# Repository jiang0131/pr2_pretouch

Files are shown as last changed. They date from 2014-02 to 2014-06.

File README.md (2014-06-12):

This repository includes components of pretouch sensing related packages that use ROS:

* **pr2_pretouch_seashell_sensors**: seashell pretouch sensor nodes
* **pr2_pretouch_optical_sensors**:	optical pretouch sensor nodes
* **pr2_pretouch_msgs**: pretouch sensor related messages
* **pr2_gripper_firmware**: the picoblaze and atmega microcontroller firmwares for the pretouch sensors
* **pr2_pretouch_sensor_hardware**: sensor hardware design files (PCB, mechanical model)
* **pr2_pretouch_grasp**: pretouch assisted grasping application

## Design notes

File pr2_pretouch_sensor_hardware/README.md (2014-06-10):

fixture_solidworks: Contains the PR2 finger mechanical design files in Solidworks for each of the pretouch sensors, so the PCB and sensor components can be fixed/mounted on the fixure.

pcb_altium: Contains the schematics and PCB layout files in Altium for each of the pretouch sensors. Bill of Materials are also included.

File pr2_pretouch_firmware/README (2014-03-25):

- seashell_effect     -- Firmware of Seashell Effect Pretouch Sensor
    + microcontroller     -- ATmega168/328 fimware
    + picoblaze           -- PicoBlaze firmware
- optical_ir          -- Firmware of Optical IR Pretouch Sensor
    + microcontroller     -- ATmega168/328 fimware
    + picoblaze           -- PicoBlaze firmware
- wg006_gripper       -- Firmware of the FPGA on the MCB of PR2 grippers which supports PicoBlaze (PicoBlaze supported >2.0)

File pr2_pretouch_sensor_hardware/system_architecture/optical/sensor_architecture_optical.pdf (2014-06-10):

Analog Signal | Digital Signal

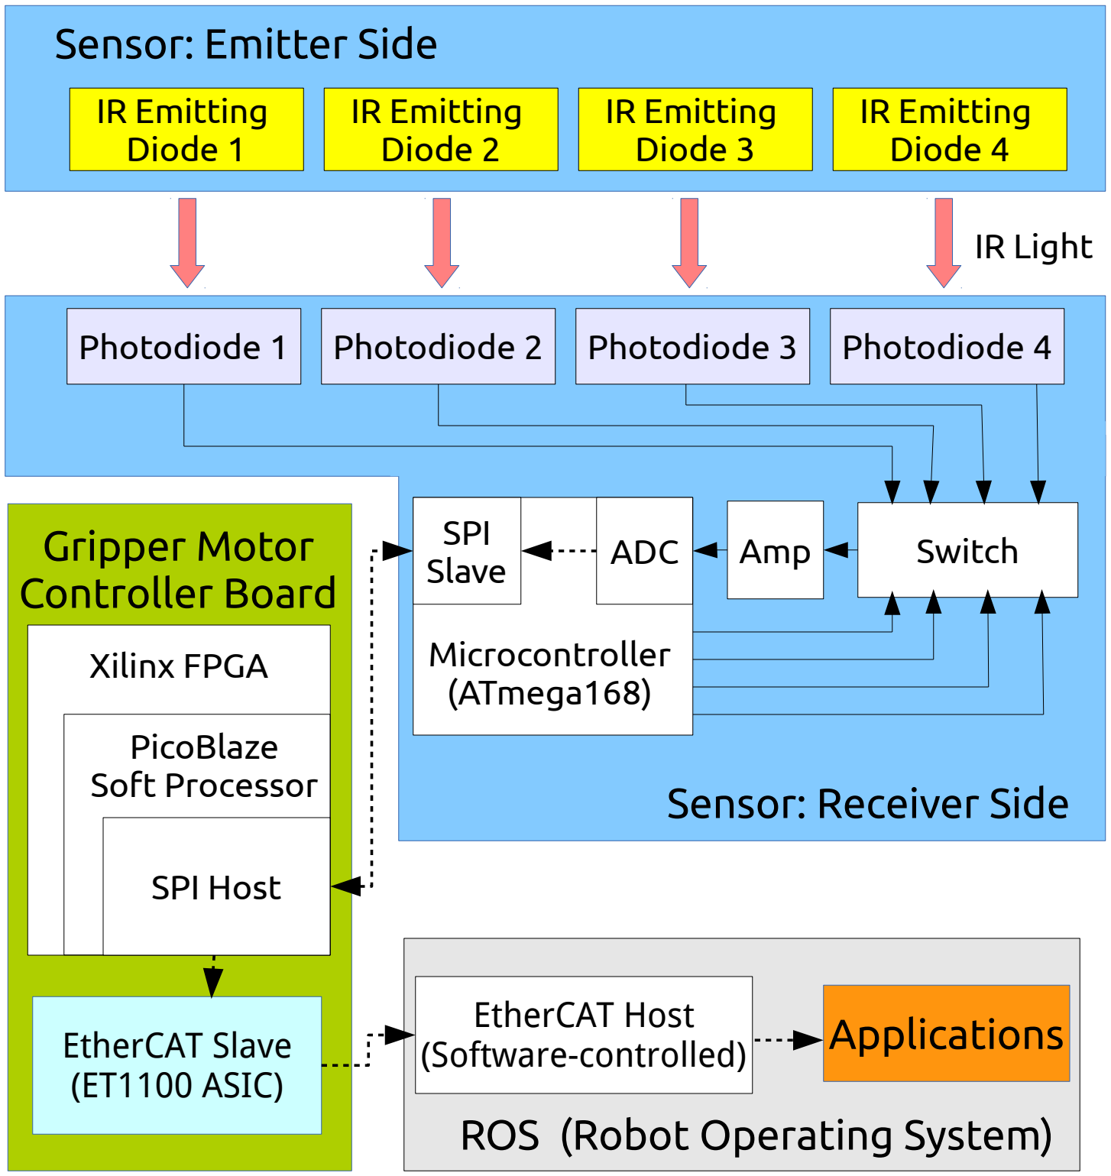
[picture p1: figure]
Gripper Motor Controller Board; Switch; Xilinx FPGA; PicoBlaze Soft Processor; SPI Host; EtherCAT Host (Software-controlled) EtherCAT Slave (ET1100 ASIC); ROS (Robot Operating System); Microcontroller (ATmega168); ADC SPI Slave; Applications; IR Emitting Diode 1; Photodiode 1; IR Emitting Diode 2; Photodiode 2; IR Emitting Diode 3; Photodiode 3; IR Emitting Diode 4; Photodiode 4; Amp; Sensor: Emitter Side; Sensor: Receiver Side; IR Light

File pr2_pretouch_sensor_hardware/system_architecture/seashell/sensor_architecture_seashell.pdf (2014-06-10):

Analog Signal | Digital Signal

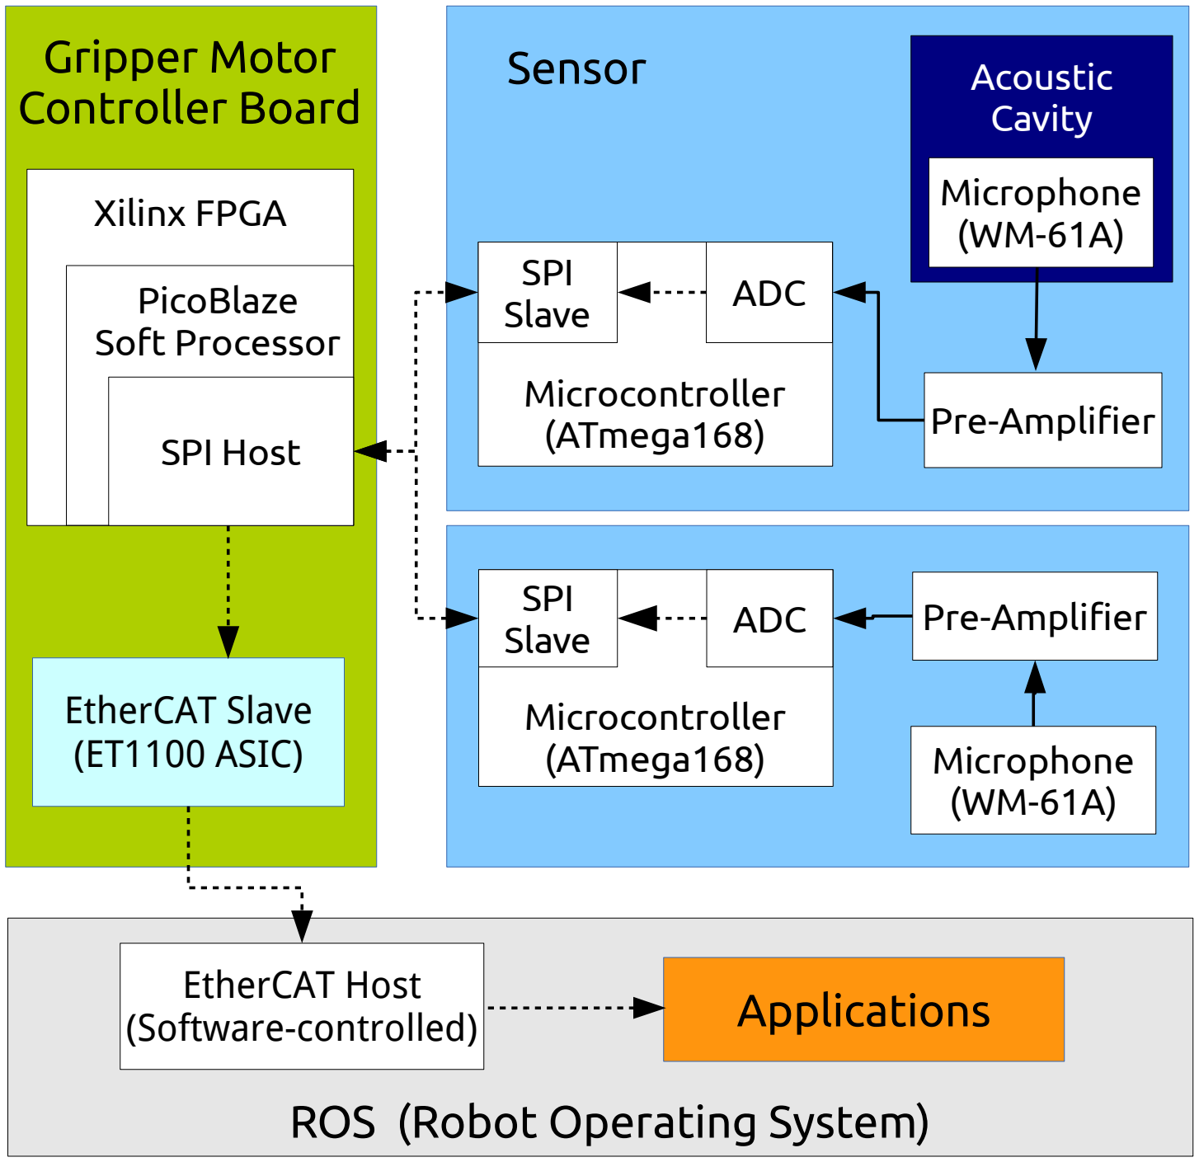
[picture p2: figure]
Gripper Motor; Controller Board; Acoustic; Cavity; Microphone (WM-61A); Pre-Amplifier; Xilinx FPGA; PicoBlaze Soft Processor; SPI Host; EtherCAT Host (Software-controlled); EtherCAT Slave (ET1100 ASIC); ROS (Robot Operating System); Microcontroller (ATmega168); ADC SPI Slave; Applications; Sensor

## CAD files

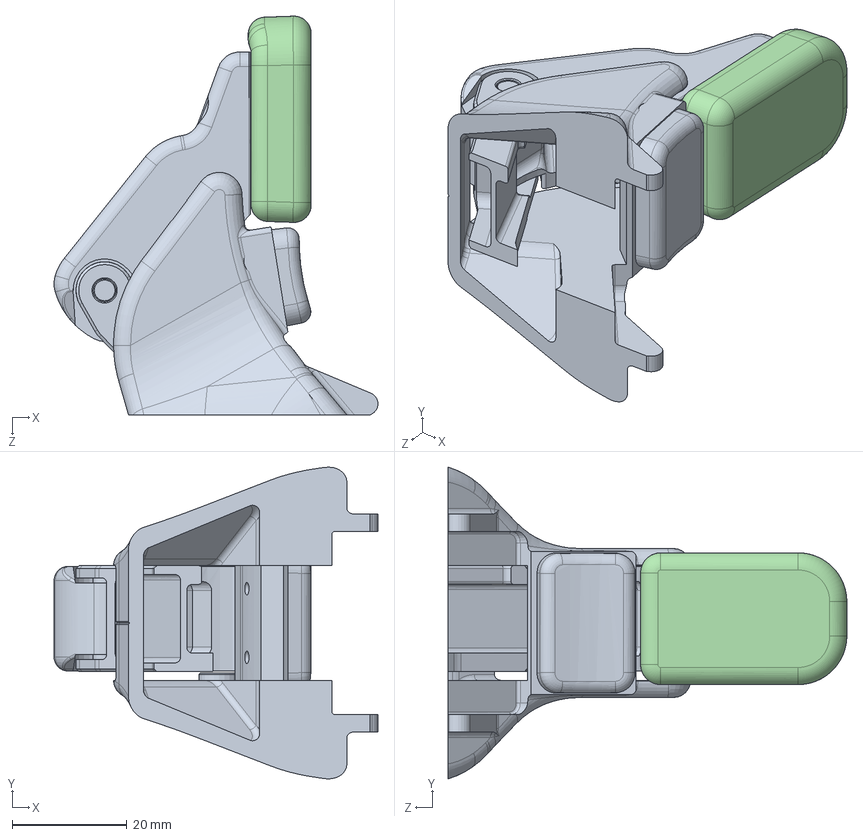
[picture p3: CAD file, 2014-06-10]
pr2_pretouch_sensor_hardware/fixture_solidworks/fixture_solidworks_pr2_original/PR2_MODULARITY_GRPR_ASM.sldasm
56.5 x 54.4 x 69.6 mm
PR2_MODULARITY_GRPR
SCR_SHCS_M3_050_8_SST_A2-70 x 4
PR2_HAND_FINGER_CORE
PR2_HAND_FINGER_RUBBER

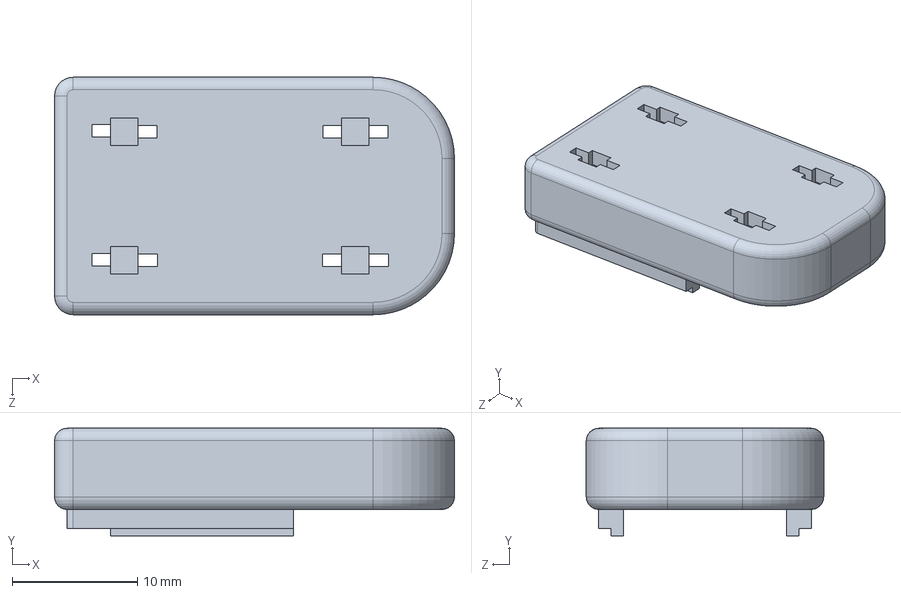
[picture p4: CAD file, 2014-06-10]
pr2_pretouch_sensor_hardware/fixture_solidworks/fixture_solidworks_optical/pr2_finger_optical.SLDPRT
32.0 x 8.60 x 19.0 mm

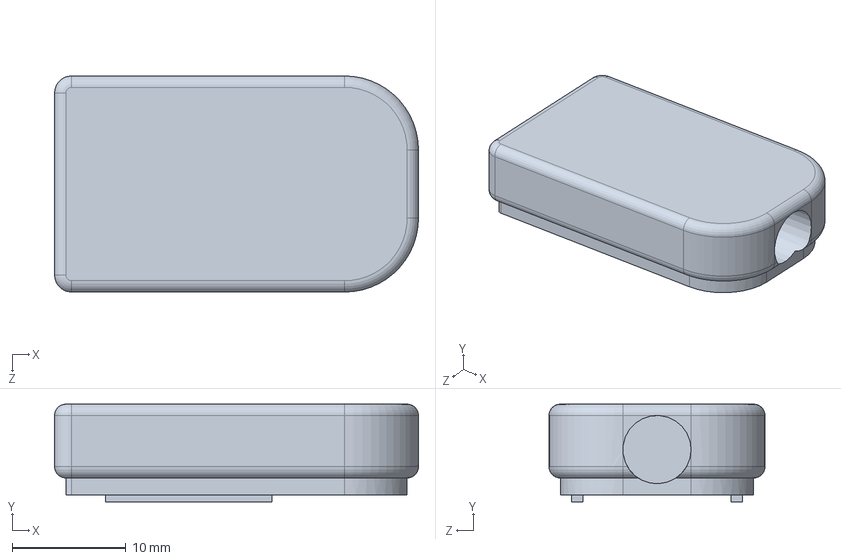
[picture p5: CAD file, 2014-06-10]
pr2_pretouch_sensor_hardware/fixture_solidworks/fixture_solidworks_seashell/pr2_finger_seashell_reference.SLDPRT
32.0 x 8.60 x 19.0 mm

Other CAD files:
pr2_pretouch_sensor_hardware/fixture_solidworks/fixture_solidworks_pr2_original/PR2_MODULARITY_GRPR.sldprt
pr2_pretouch_sensor_hardware/fixture_solidworks/fixture_solidworks_seashell/pr2_finger_seashell_sensing.SLDPRT

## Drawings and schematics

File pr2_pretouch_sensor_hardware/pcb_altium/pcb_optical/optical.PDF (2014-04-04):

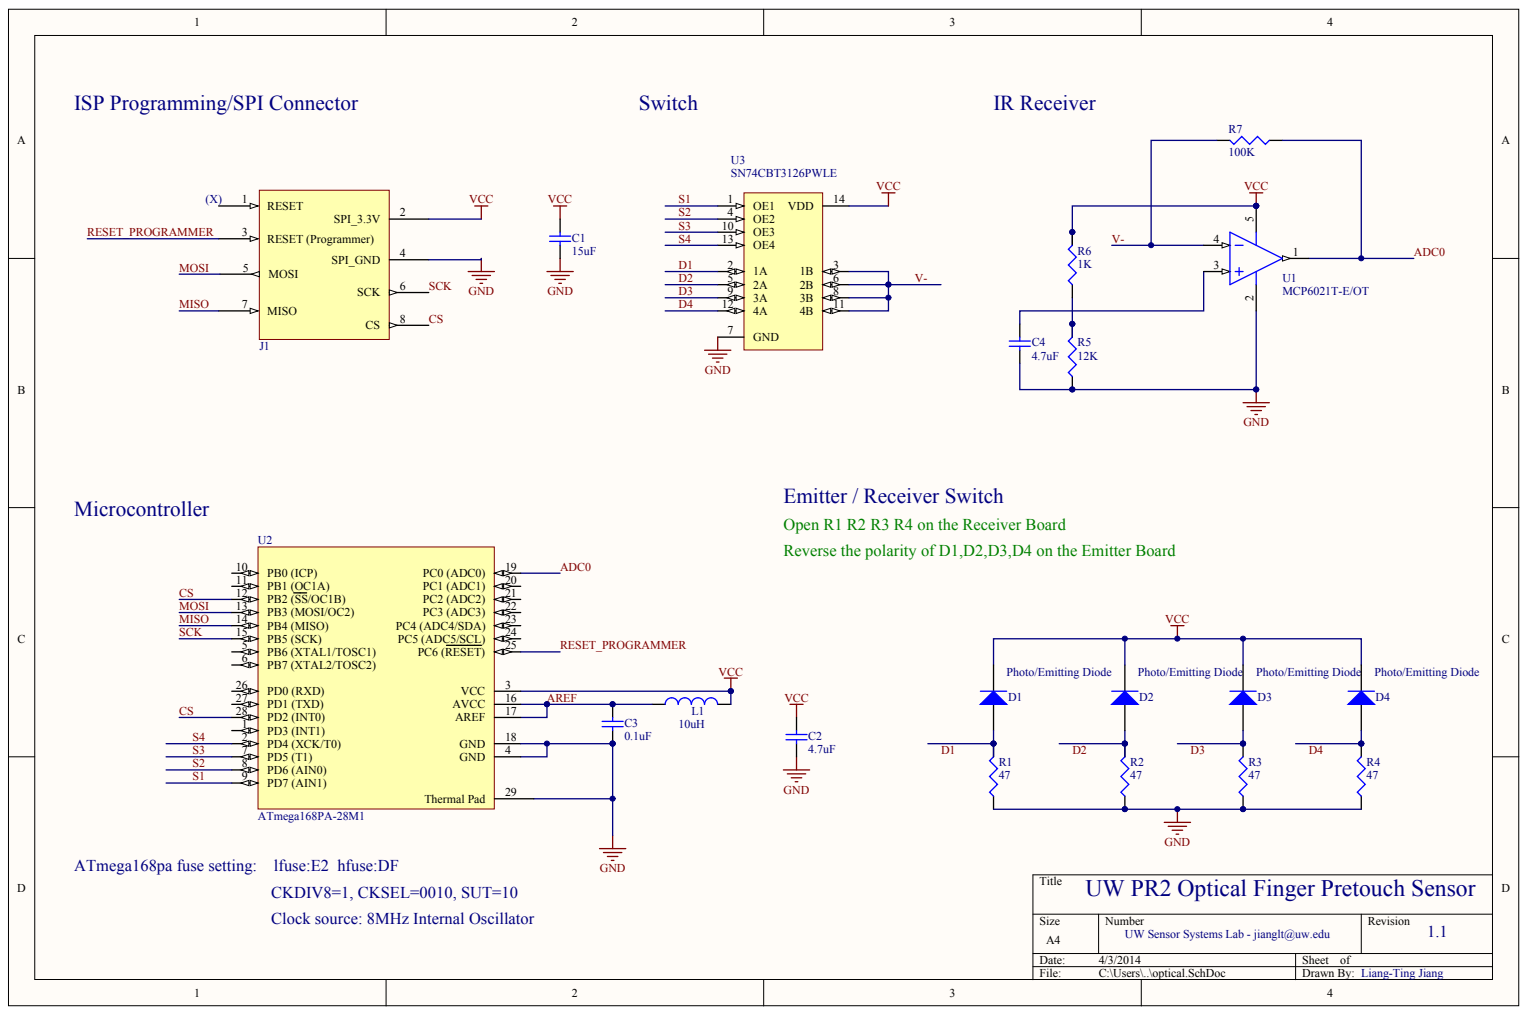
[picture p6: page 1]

ISP Programming/SPI Connector

Open R1 R2 R3 R4 on the Receiver Board
Reverse the polarity of D1,D2,D3,D4 on the Emitter Board

ATmega168pa fuse setting: lfuse:E2 hfuse:DF

Title
UW PR2 Optical Finger Pretouch Sensor

CKDIV8=1, CKSEL=0010, SUT=10
Clock source: 8MHz Internal Oscillator

Size A4 | Number UW Sensor Systems Lab - jianglt@uw.edu | Revision 1.1

Date: 4/3/2014 | Sheet of
File: C:\Users\. .\optical.SchDoc | Drawn By: Liang-Ting Jiang

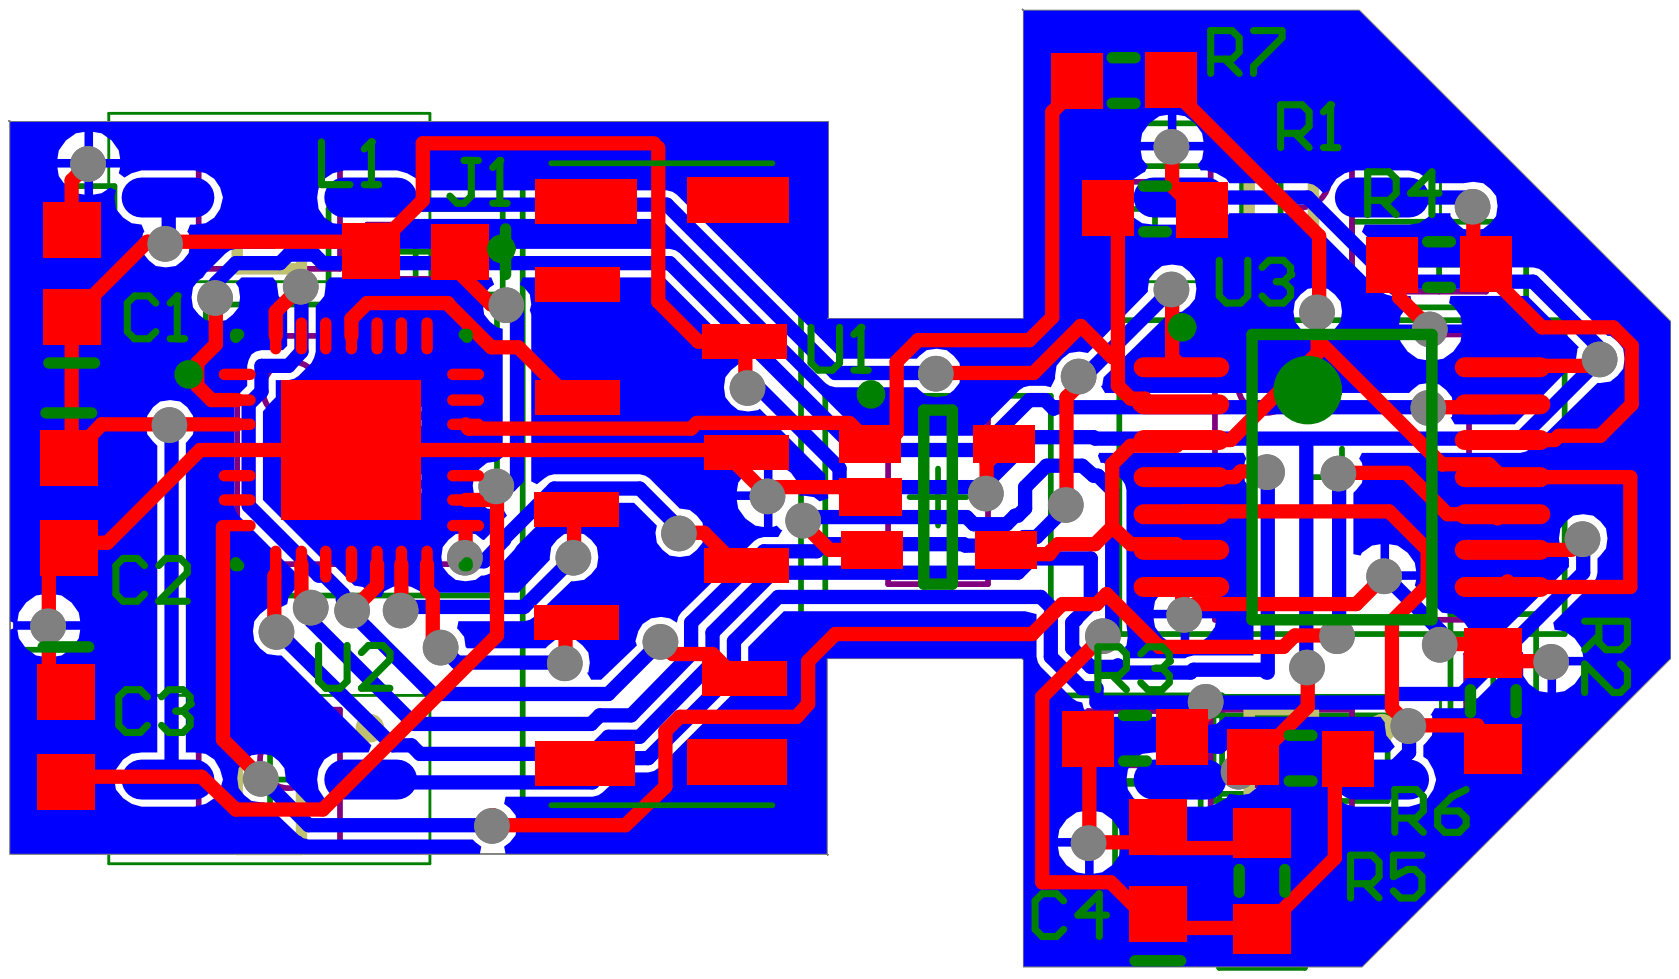
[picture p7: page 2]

Comment | Description | Designator | Footprint | LibRef | Quantity
15uF | 0603 SMD Capacitor | C1 | CAPC1608N | Cap Semi | 1
4.7uF | 0603 SMD Capacitor | C2, C4 | CAPC1608N | Cap Semi | 2
0.1uF | 0603 SMD Capacitor | C3 | CAPC1608N | Cap Semi | 1
Photo/Emitting Diode | Emitting/Photo Diode 940nm Gullwing | D1, D2, D3, D4 | Vishay VEMD/VSMB footprint | Diode | 4
FFC 8-PIN Connector (1mm) | FFC 8-PIN Connector (1mm) (SMT) | J1 | Hirose FFC connector 8-Pin | FFC Connector-8Pin-SMT-1mm | 1
10uH | 0603 SMD Inductor | L1 | INDC1608N | Inductor | 1
47 | 0603 SMD Resistor | R1, R2, R3, R4 | RESC1608N | Res3 | 4
12K | 0603 SMD Resistor | R5 | RESC1608N | Res3 | 1
1K | 0603 SMD Resistor | R6 | RESC1608N | Res3 | 1
100K | 0603 SMD Resistor | R7 | RESC1608N | Res3 | 1
MCP6021T-E/OT | Rail-to-Rail Input/Output, 10 MHz Operational Amplifier, 5-Pin SOT-23, Extended Temperature, Tape and Reel | U1 | SOT-23-OT5_N | MCP6021T-E/OT | 1
ATmega168PA-28M1 | 8-Bit AVR Microcontroller with 8K Bytes of In-System Programmable Flash Memory | U2 | | ATmega168-28M1 | 1
SN74CBT3126PWLE | Quadruple FET Bus Swit | U3 | PW014_N | SN74CBT3126PWLE | 1

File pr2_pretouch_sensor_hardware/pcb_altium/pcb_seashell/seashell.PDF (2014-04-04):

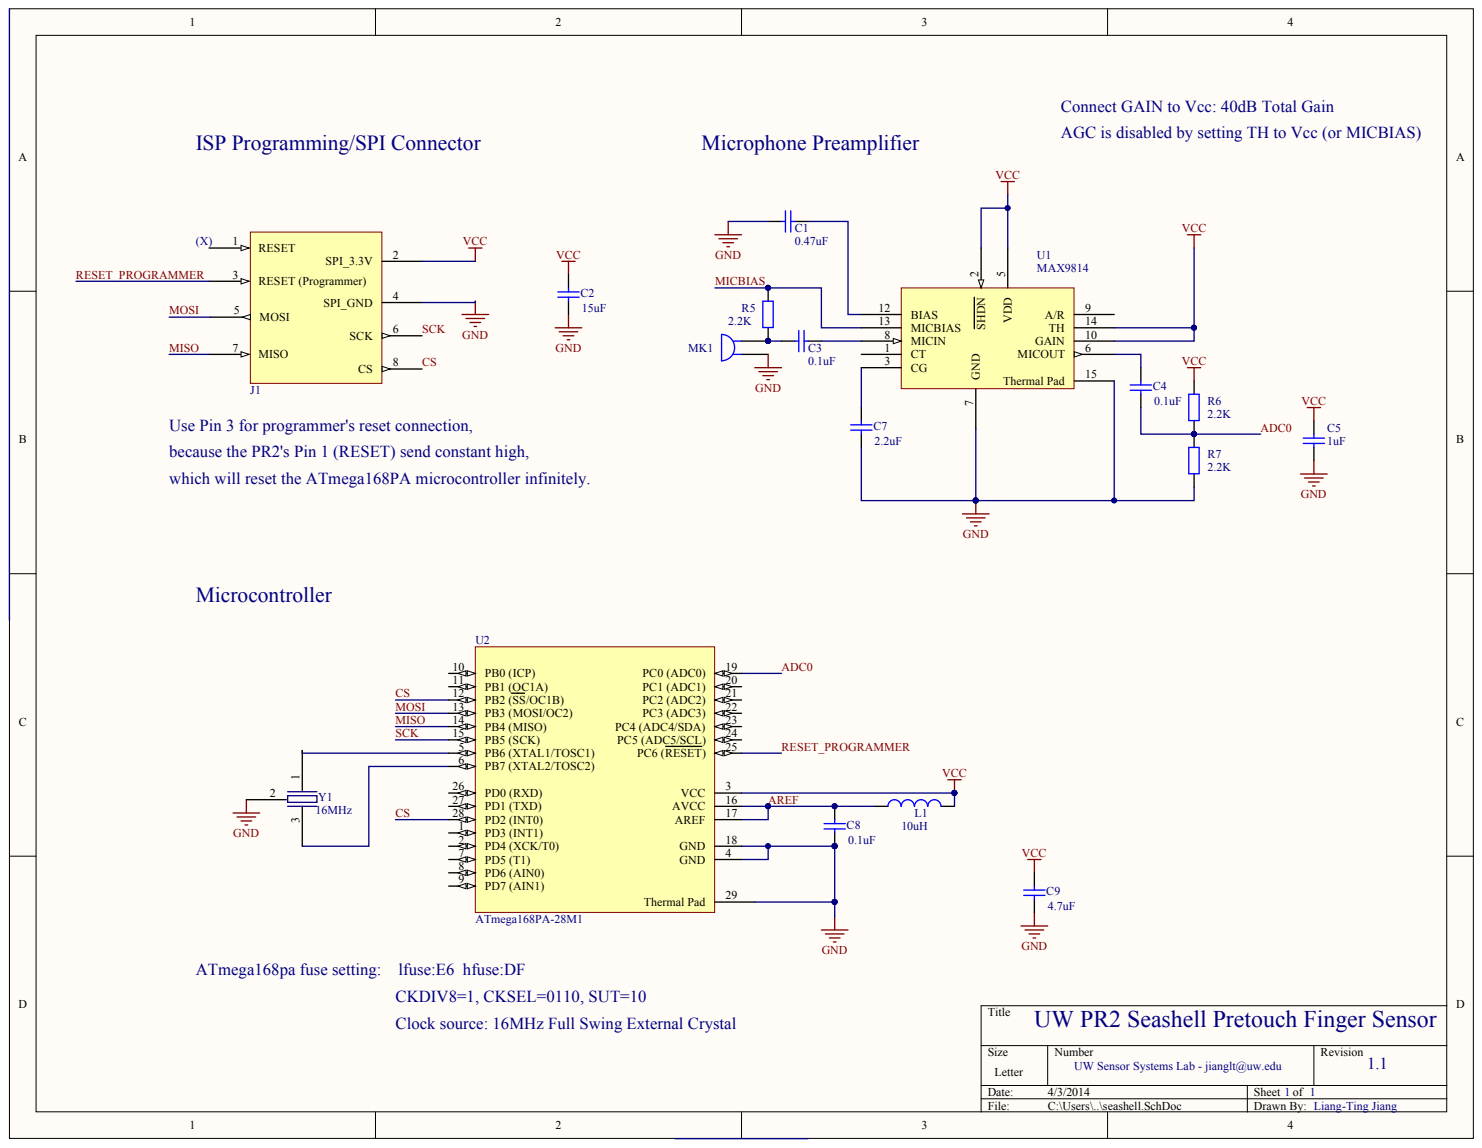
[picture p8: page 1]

Connect GAIN to Vcc: 40dB Total Gain
AGC is disabled by setting TH to Vcc (or MICBIAS)

BIAS 12 BIAS 13 MIC C T C G | TH GAIN MICOUT
MICIN 8 | 14

Use Pin 3 for programmer's reset connection,
because the PR2's Pin 1 (RESET) send constant high,
which will reset the ATmega168PA microcontroller infinitely.

ATmega168pa fuse setting: lfuse:E6 hfuse:DF

CKDIV8=1, CKSEL=0110, SUT=10
Clock source: 16MHz Full Swing External Crystal

Title
UW PR2 Seashell Pretouch Finger Sensor

UW Sensor Systems Lab - jianglt@uw.edu

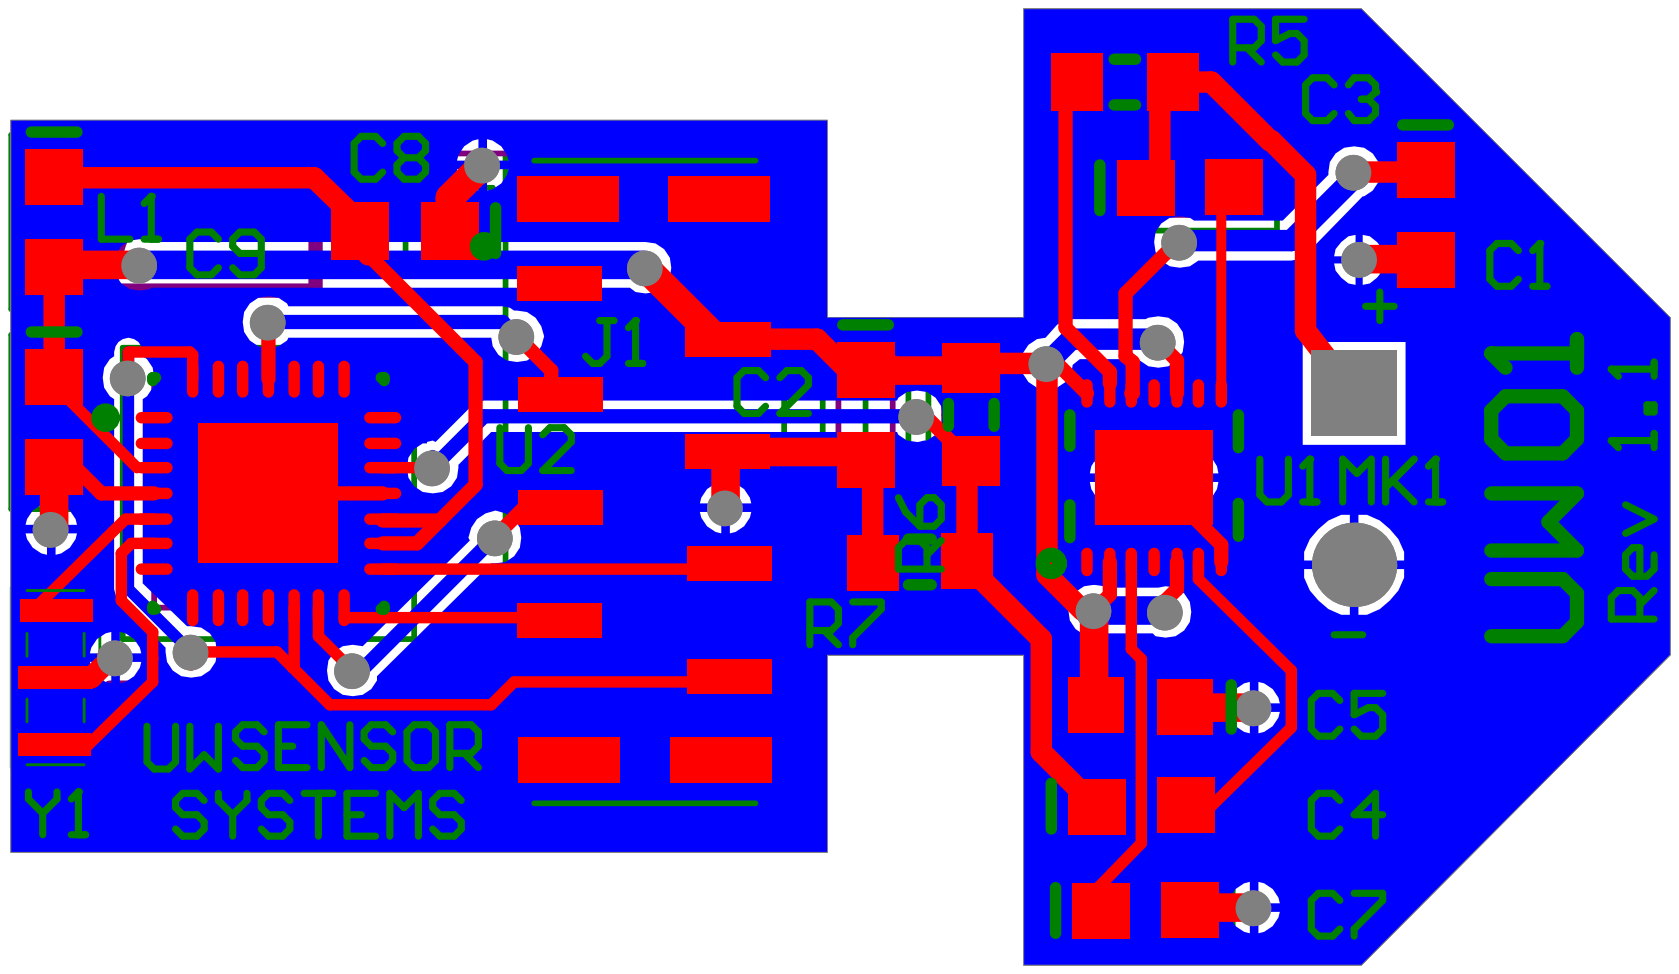
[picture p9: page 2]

Comment | Description | Designator | Footprint | LibRef | Quantity
0.47uF | 0603 SMD Capacitor | C1 | CAPC1608N | Cap | 1
15uF | 0603 SMD Capacitor | C2 | CAPC1608N | Cap | 1
0.1uF | 0603 SMD Capacitor | C3, C4, C8 | CAPC1608N | Cap | 3
1uF | 0603 SMD Capacitor | C5 | CAPC1608N | Cap | 1
2.2uF | 0603 SMD Capacitor | C7 | CAPC1608N | Cap | 1
4.7uF | 0603 SMD Capacitor | C9 | CAPC1608N | Cap | 1
FFC 8-PIN Connector (1mm) | FFC 8-PIN Connector (1mm) (SMT) | J1 | Hirose FFC connector 8-Pin | FFC Connector-8Pin-SMT-1mm | 1
10uH | 0603 SMD Inductor | L1 | INDC1608N | Inductor | 1
Panasonic WM-61A | Electret Microphone | MK1 | PIN2 | Mic1 | 1
2.2K | 0603 SMD Resistor | R5, R6, R7 | RESC1608N | Res2 | 3
MAX9814 | Microphone Amplifier with AGC and Low-Noise Microphone Bias | U1 | QFN-14-Minnimum-Solder-Mask-Relief | MAX9814 | 1
ATmega168PA-28M1 | 8-Bit AVR Microcontroller with 8K Bytes of In-System Programmable Flash Memory | U2 | 28M1 | ATmega168-28M1 | 1
AVX PRQC16.00SR5010X000 16MHz Ceramic Chip ResY1 | | | AVX-PRQC Ceramic ResoCeram ic Resonator SMT ( | | 1

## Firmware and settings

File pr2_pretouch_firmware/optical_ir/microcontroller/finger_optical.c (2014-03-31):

/*
Firmware for the receiver side of PR2 optical sensor finger.
Sends ADC signal from SPI Slave (itself) to SPI Master (PicoBlaze)
microcontroller: Atmel AVR ATMega168(P)/328(P)
@Liang-Ting Jiang 01-16-2014
*/

#include <avr/io.h> 
#include <avr/interrupt.h> 
#include <util/delay.h>

uint8_t SPI_SlaveReceive(void);
volatile char ch;
volatile uint8_t idx;

int main (void) 
{  
  /********* SWITCH SELECT OUTPUT ********/
  DDRD |= (1<<DDD4) | (1<<DDD5) | (1<<DDD6) | (1<<DDD7); //set PD4-7 as output for switch selects

  /**** EXTERNAL INTERRUPT *****/
  DDRD &= ~(1<<DDD2); //setup External interrupt 0 as Input (PD2) (clear bit 2)
  PORTD |= (1<<PD2); //set PD2(INT0) to high (impedance) (pull-up resistor is activated)
  EIMSK |= (1<<INT0);  //enable INT0
  EICRA |= (1<<ISC01); //INT0 triggered on falling edge

  /*********** ADC ***********/
  ADCSRA |= (1 << ADPS2) | (1 << ADPS1) | (1 << ADPS0); // ADC prescaler=128 - 62.5KHz sample rate @ 8MHz 
  //ADCSRA |= (1 << ADPS2) | (1 << ADPS1); // (8M/64)
  //ADCSRA |= (1 << ADPS2) | (1 << ADPS0); // (8M/32)
  //ADCSRA |= (1 << ADPS2); // (8M/16)
  //ADCSRA |= (1 << ADPS1) | (1 << ADPS0); // (8M/8)
  ////ADCSRA |= (1 << ADPS1); // (8M/4)
  //ADCSRA |= (1 << ADPS0); // (8M/2)   

  ADMUX |= (1 << REFS0); // Set ADC reference to AVCC 
  ADMUX |= (1 << ADLAR); // Left adjust ADC result to allow easy 8 bit reading 
  //No MUX values change required to use ADC0 
  //ADCSRA |= (1 << ADATE);  // Set ADC to Free-Running Mode 
  ADCSRA |= (1 << ADEN);  // Enable ADC 
  ADCSRA |= (1 << ADIE);  // Enable ADC Interrupt 
  sei();   // Enable Global Interrupts 
  //ADCSRA |= (1 << ADSC);  // Start A2D Conversions 

  /********** SPI ***********/
  DDRB = (1<<DDB4); // MISO output
  SPCR = (1<<SPE); // Enable SPI 

  /*****fixed ADC ch (for testing only) ******/
  //PORTD |= _BV(7);
  //PORTD |= _BV(6);
  //PORTD |= _BV(5);
  //PORTD |= _BV(4);

  ch = 1;  
  idx = 2;

  /* MAIN LOOP*/
  for(;;)  // Loop Forever 
  { 
  } 
} 

ISR(INT0_vect) {

  // Before an ADC conversion, send signal to switch to select the desired channel
  // Order: PD7->PD6->PD5->PD4 (CH1->CH2->CH3->CH4)
  // We want to have the ADC samples on channels (ch) in this order: 1-2-3-4
  // The SPI master Picoblaze send data (idx) by the order: 4-3-2-1
  // Ideally, we want the variables ch and idx in these orders:
  // idx: 4 3 2 1 4 3 2 1
  // ch : 1 2 3 4 1 2 3 4  
  // However, a new idx is given after the ADC os sampled using ch
  // Therefor, the idx should indicate the "next" ch we want to sample
  // ch is used before getting the new idx, so ch is lag behind the idx by 1 location
  // ch : 1 2 3 4 1 2 3 4
  // idx:   4 3 2 1 4 3 2 1
  // These result in the following mapping:
  if (idx == 1) {
    ch = 2;
  } else if (idx == 2) {
    ch = 1;
  } else if (idx == 3) {
    ch = 4; 
  } else { //idx == 4
    ch = 3;
  } 

  // Send High signal to the switch to select which channel to open
  PORTD |= _BV(8-ch);
  
  // Wait for the switch working and the signal going through to opamp
  _delay_us(1);

  // Single ADC conversion
  ADCSRA |= (1 << ADSC); //single ADC conversion

  // Wait for the ADC to finish
  _delay_us(3);

  // De-select the current channel
  PORTD &= ~_BV(8-ch);

  // wait for SPI transmission finish and get data
  idx = SPI_SlaveReceive();
}

ISR(ADC_vect) { 
  // move the ADC value to SPI buffer
  SPDR = ADCH;
} 

uint8_t SPI_SlaveReceive(void) {
  // Wait for reception complete (until SPIF is set)
  while(!(SPSR & (1<<SPIF)));
  // Return Data Register
  return SPDR;
}

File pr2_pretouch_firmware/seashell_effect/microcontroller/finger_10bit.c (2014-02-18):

/*
Firmware for transmitting ADC signal from SPI Slave (itself) to SPI Master (PicoBlaze)
microcontroller: Atmel AVR ATMega328P/168
@author: Liang-Ting Jiang
*/

#include <avr/io.h> 
#include <avr/interrupt.h> 
#include <util/delay.h>
char SPI_SlaveReceive(void);
void check_ADCH(void);

int main (void) 
{  
   /********* LED OUTPUT ********/
   //DDRD |= (1<<DDD7) | (1<<DDD6); //set all PD6, PD7 to LED output for debugging

   /**** EXTERNAL INTERRUPT *****/
   DDRD &= ~(1<<DDD2); // setup External interrupt 0 as Input (PD2)
   PORTD |= (1<<PD2); // set PD2(INT0) to high (impedance) (pull-up resistor is activated)
   EIMSK |= (1 << INT0);  // Enable INT0
   EICRA |= (1 << ISC01); // Trigger on falling edge of INT0

   /*********** ADC ***********/
   //ADCSRA |= (1 << ADPS2) | (1 << ADPS1) | (1 << ADPS0); // Set ADC prescaler to 128 - 125KHz sample rate @ 16MHz 
   //ADCSRA |= (1 << ADPS2) | (1 << ADPS1); // (16M/64=250KHz)
   //ADCSRA |= (1 << ADPS2) | (1 << ADPS0); // (16M/32=500KHz) (Too fast..the concerted value is wrong)
   //ADCSRA |= (1 << ADPS2); // (16M/16=1Mhz)
   //ADCSRA |= (1 << ADPS1) | (1 << ADPS0); // (16M/8=2Mhz)
   //ADCSRA |= (1 << ADPS0); // ( 16M/2=8Mhz)   
   ADCSRA |= (1 << ADPS1); // ( 16M/4=4Mhz)
   ADMUX |= (1 << REFS0); // Set ADC reference to AVCC 
   //ADMUX |= (1 << ADLAR); // Left adjust ADC result to allow easy 8 bit reading 
   // No MUX values needed to be changed to use ADC0 
   //ADCSRA |= (1 << ADATE);  // Set ADC to Free-Running Mode 
   ADCSRA |= (1 << ADEN);  // Enable ADC 
   ADCSRA |= (1 << ADIE);  // Enable ADC Interrupt 
   sei();   // Enable Global Interrupts 
   //ADCSRA |= (1 << ADSC);  // Start A2D Conversions 

   /********** SPI ***********/
   DDRB = (1<<DDB4); // MISO output
   SPCR = (1<<SPE); //Enable SPI 


   /* MAIN LOOP*/
   for(;;)  // Loop Forever 
   { 
   } 
} 

ISR(INT0_vect) {
  ADCSRA |= (1 << ADSC); //single ADC conversion
}

void check_ADCH(void) {
  if (SPDR < 120) {
    PORTD |=  (1<<PD6);
    PORTD &= ~(1<<PD7);
  }
  else {
    PORTD |=  (1<<PD7);
    PORTD &= ~(1<<PD6);
  }
}


ISR(ADC_vect) { 
  //read ADCL to SPDR
  SPDR = ADCL;

  //wait for SPI transmission (8-bits)
  SPI_SlaveReceive();

  // read ADCH to SPDF
  SPDR = ADCH;

  //wait for SPI transmission finish
  SPI_SlaveReceive();

} 


char SPI_SlaveReceive(void) {
  // Wait for reception complete (until SPIF is set)
  while(!(SPSR & (1<<SPIF)))
  ;
  // Return Data Register
  return SPDR;
}

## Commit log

2014-01-27 add optical sensor pubisher
2014-01-27 add optical sensor publisher
2014-02-18 add finger_10bit.c
2014-03-12 add analyze scripts for both gripper and pyaudio paths
2014-03-25 add firmware for optical IR sensor
2014-03-27 update the optical ir sensor microcontroller firmware
2014-03-28 update the firmwares for optical sensor so that the sensing order is fixed
    [finger.c, finger_optical.c]
2014-03-31 handshaking between master/slave to fix channels
    [finger_optical.c]
2014-04-04 Add pretouch sensor PCB Altium files
    [IPC-7352 Chip_Capacitor_N.PcbLib, IPC-7352 Chip_Inductor_N.PcbLib, IPC-7352 Chip_Resistor_N.PcbLib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]
2014-06-10 move pcb and solidworks files to pr2_pretouch_sensor_hardware
    [IPC-7352 Chip_Capacitor_N.PcbLib, IPC-7352 Chip_Inductor_N.PcbLib, IPC-7352 Chip_Resistor_N.PcbLib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]
2014-06-10 move seashell sensor message to the seashell package
2014-06-12 fix launch files for seashell sensor
